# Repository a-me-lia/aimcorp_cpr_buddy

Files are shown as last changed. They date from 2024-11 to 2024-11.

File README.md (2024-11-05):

# Production Instructions

The files in the `/production` folder are ready for ordering at JLCPCB or most other PCB brokering services.

- **Board Design**: This board is designed as a 2-layer PCB. The quoting software should automatically select the minimum tolerances needed.
- **BOM Handling**: 
    - After uploading the BOM, if a component did not autopopulate, locate the corresponding designator in the BOM file.
    - Use the LCSC part number from the BOM to search in the JLC Parts library for an identical component.
    - LCSC "C-numbers" can be directly used in JLCPCB for part selection.

# Programming Instructions

This board is compatible with a standard 6-pin FTDI breakout for programming.

- **Programming Port**: The programming port is not populated with a pin header, allowing direct insertion of the FTDI board.
- **Bootloader Mode Strapping**: Refer to the [ESP-12F datasheet](https://www.espressif.com/sites/default/files/documentation/0a-esp8266ex_datasheet_en.pdf) for details on bootloader mode strapping.
    - All physical interfaces for pin strapping are accessible via a 4-pin interface on the board.

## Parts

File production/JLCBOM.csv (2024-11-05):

Comment | Designator | Footprint | JLCPCB Part #
BS-08-B2AA001 | BT1 | BS-08-B2AA001 | C964777
C100n | C1,C2,C4,C5,C6,C7 | Capacitor_SMD:C_0402_1005Metric | C60474
C1u | C3 | Capacitor_SMD:C_0402_1005Metric | C14445
BAT54C-7-F | D1 | Package_TO_SOT_SMD:SOT-23 | C556168
Conn_01x04_Pin | J2 | PinHeader_1x04_P2.54mm_Vertical | C6332197
Lf | L1 | Inductor_SMD:L_0402_1005Metric | C2885921
FNR4030S4R7MT | L2 | Inductor_SMD:L_Changjiang_FNR4030S | C167874
R330 | R1,R11,R14 | Resistor_SMD:R_0402_1005Metric | C25104
R4k7 | R2,R3,R7,R9 | Resistor_SMD:R_0402_1005Metric | C25940
R68k | R4 | Resistor_SMD:R_0402_1005Metric | C36871
R22k | R5,R13,R15 | Resistor_SMD:R_0402_1005Metric | C82868
R47k | R6 | Resistor_SMD:R_0402_1005Metric | C93943
R100R | R12 | Resistor_SMD:R_0402_1005Metric | C106232
ESP-12F | U1 | RF_Module:ESP-12E | C82891
ADS1110A0IDBVR | U2 | SOT95P280X145-6N | C16598
TPS613221ADBV | U3 | Package_TO_SOT_SMD:SOT-23-5 | C2071121

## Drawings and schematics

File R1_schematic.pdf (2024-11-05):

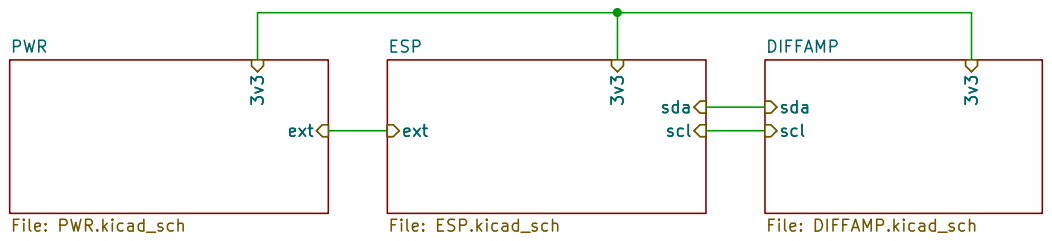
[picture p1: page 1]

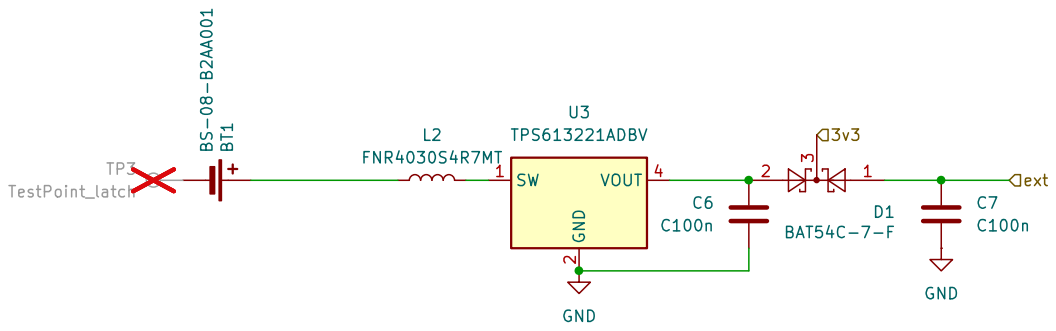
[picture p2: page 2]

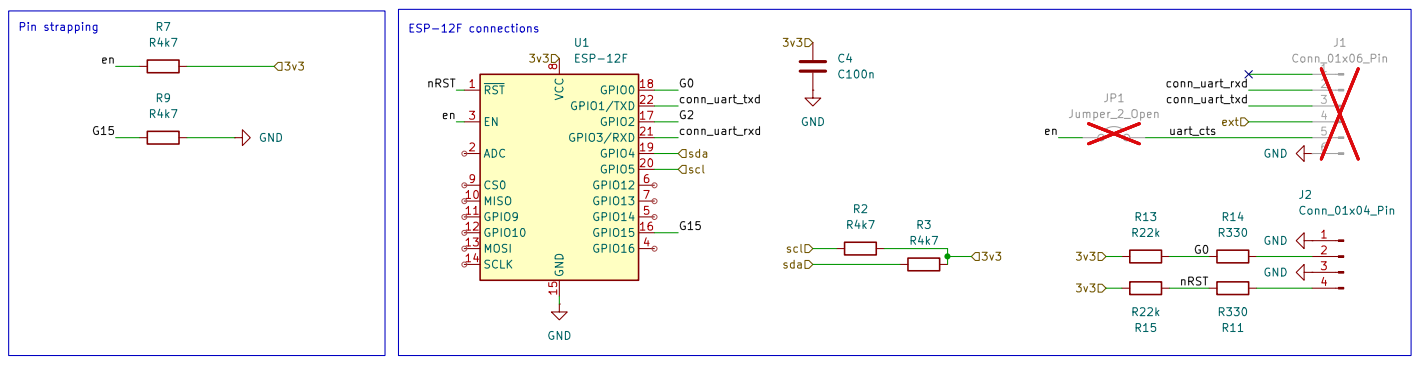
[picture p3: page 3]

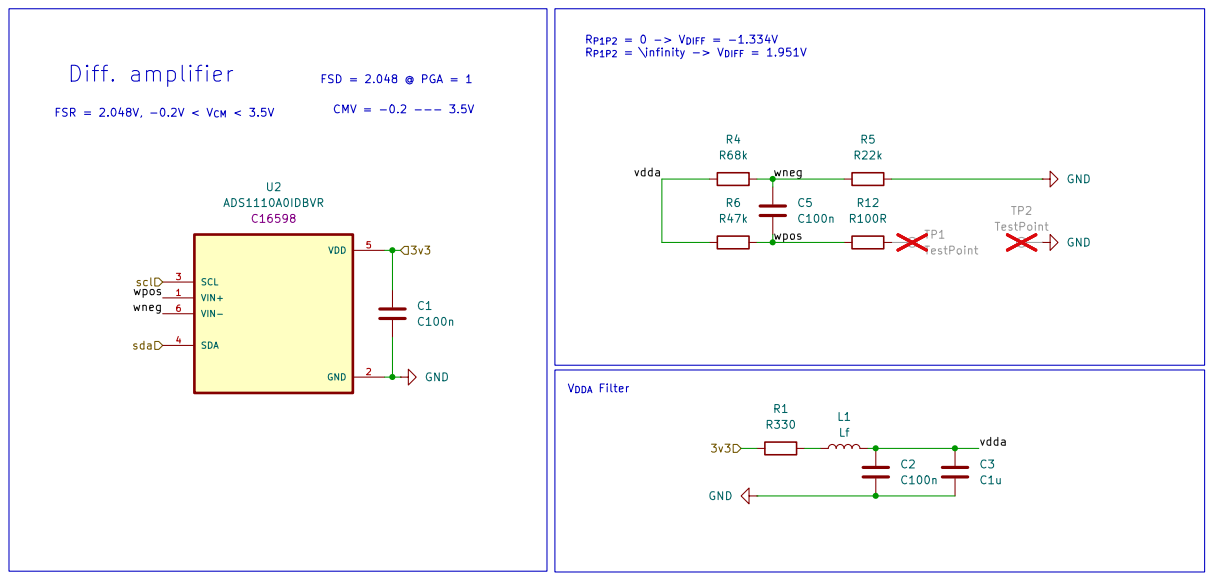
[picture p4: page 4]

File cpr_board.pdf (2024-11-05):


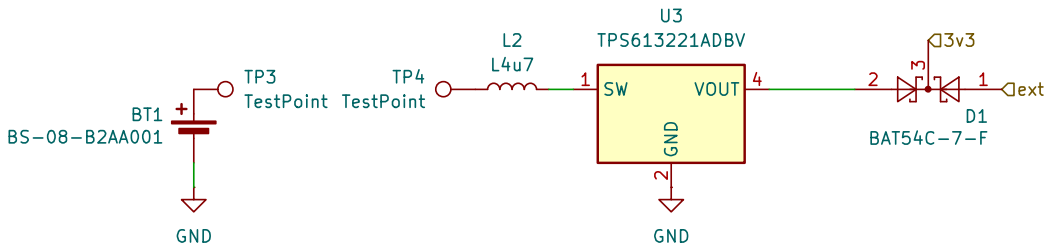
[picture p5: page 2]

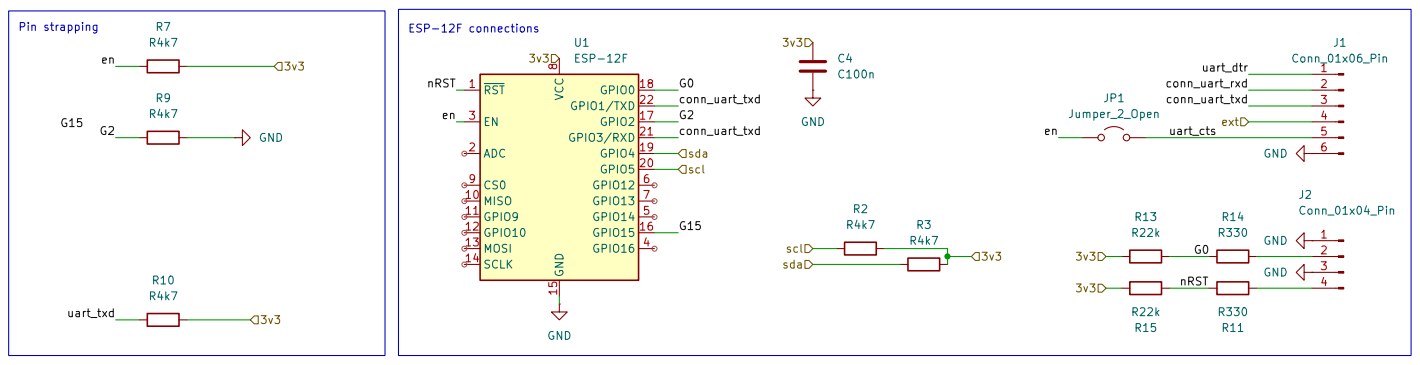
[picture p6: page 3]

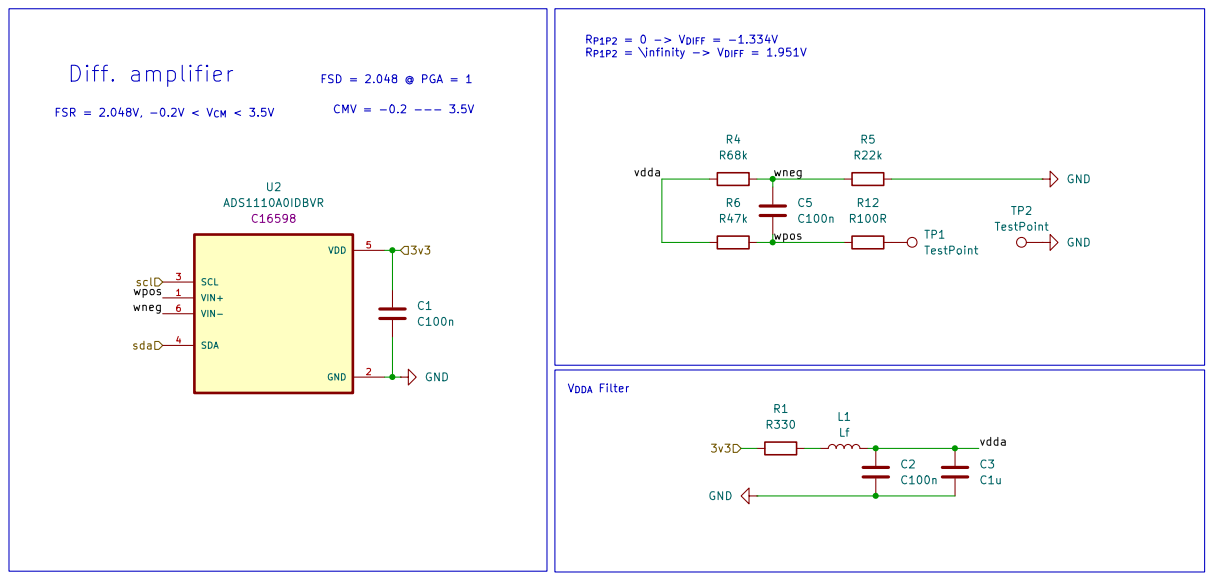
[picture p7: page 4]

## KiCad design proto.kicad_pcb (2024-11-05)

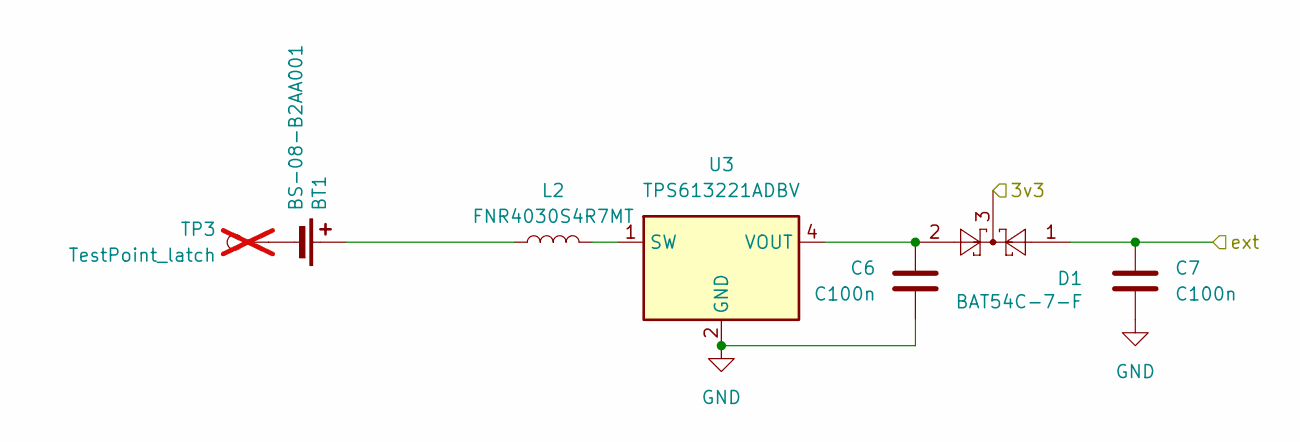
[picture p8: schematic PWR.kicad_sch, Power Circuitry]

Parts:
BT1: BS-08-B2AA001; LCSC C964777
C6, C7: C100n; C_0402_1005Metric; LCSC C60474
D1: BAT54C-7-F; SOT-23; LCSC C556168
L2: FNR4030S4R7MT; L_Changjiang_FNR4030S; LCSC C167874
TP3: TestPoint_latch; TestPoint_Bridge_Pitch2.0mm_Drill0.7mm; not fitted
U3: TPS613221ADBV; SOT-23-5; LCSC C2071121

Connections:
/DIFFAMP/3v3: D1.3; also elsewhere on the board
/ESP/ext: C7.1, D1.1; also elsewhere on the board
GND: C6.2, C7.2, U3.2 (GND); also elsewhere on the board
unnamed: BT1.+, L2.1
unnamed: BT1.-, TP3.1
unnamed: L2.2, U3.1 (SW)
unnamed: C6.1, D1.2, U3.4 (VOUT)

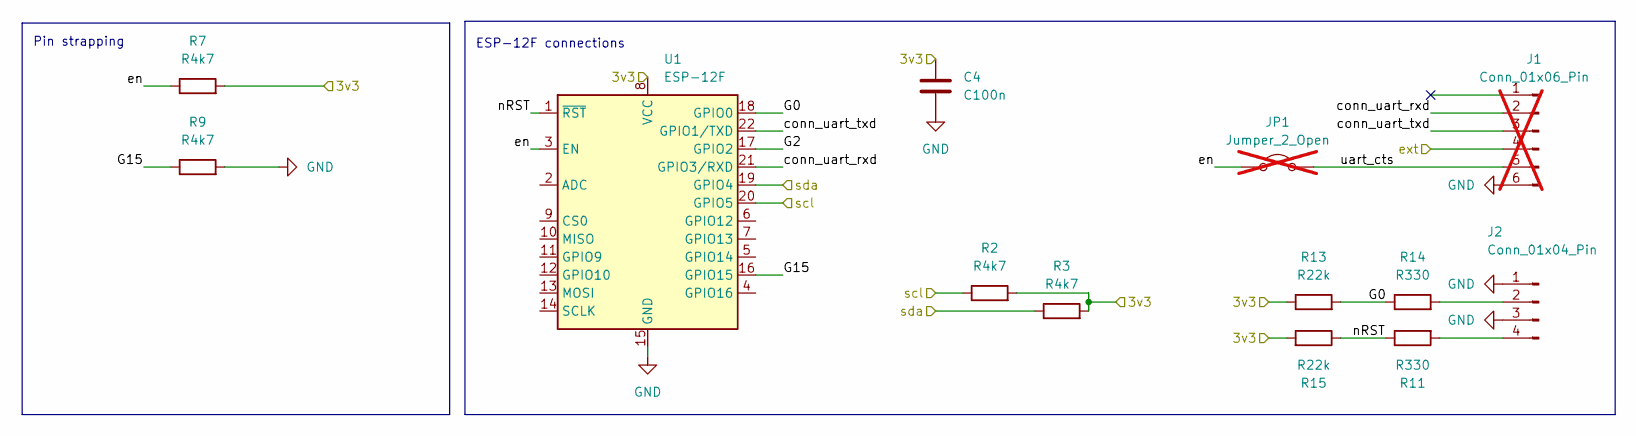
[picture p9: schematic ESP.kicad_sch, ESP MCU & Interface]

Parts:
C4: C100n; C_0402_1005Metric; LCSC C60474
J1: Conn_01x06_Pin; PinHeader_1x06_P2.54mm_Vertical; not fitted
J2: Conn_01x04_Pin; PinHeader_1x04_P2.54mm_Vertical; LCSC C6332197
JP1: Jumper_2_Open; SolderJumper-2_P1.3mm_Open_TrianglePad1.0x1.5mm; not fitted
R2, R3, R7, R9: R4k7; R_0402_1005Metric; LCSC C25940
R11, R14: R330; R_0402_1005Metric; LCSC C25104
R13, R15: R22k; R_0402_1005Metric; LCSC C82868
U1: ESP-12F; ESP-12E; LCSC C82891

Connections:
/DIFFAMP/3v3: C4.1, R2.2, R3.2, R7.2, R13.1, R15.2, U1.8 (VCC); also elsewhere on the board
/DIFFAMP/scl: R2.1, U1.20 (GPIO5); also elsewhere on the board
/DIFFAMP/sda: R3.1, U1.19 (GPIO4); also elsewhere on the board
/ESP/G0: R13.2, R14.1, U1.18 (GPIO0)
/ESP/G2: U1.17 (GPIO2)
/ESP/G15: R9.1, U1.16 (GPIO15)
/ESP/conn_uart_rxd: J1.2, U1.21 (GPIO3/RXD)
/ESP/conn_uart_txd: J1.3, U1.22 (GPIO1/TXD)
/ESP/en: JP1.1 (A), R7.1, U1.3 (EN)
/ESP/ext: J1.4; also elsewhere on the board
/ESP/nRST: R11.1, R15.1, U1.1 (~RST)
/ESP/uart_cts: J1.5, JP1.2 (B)
GND: C4.2, J1.6, J2.1, J2.3, R9.2, U1.15 (GND); also elsewhere on the board
unnamed: J2.2, R14.2
unnamed: J2.4, R11.2

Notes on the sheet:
Pin strapping
ESP-12F connections

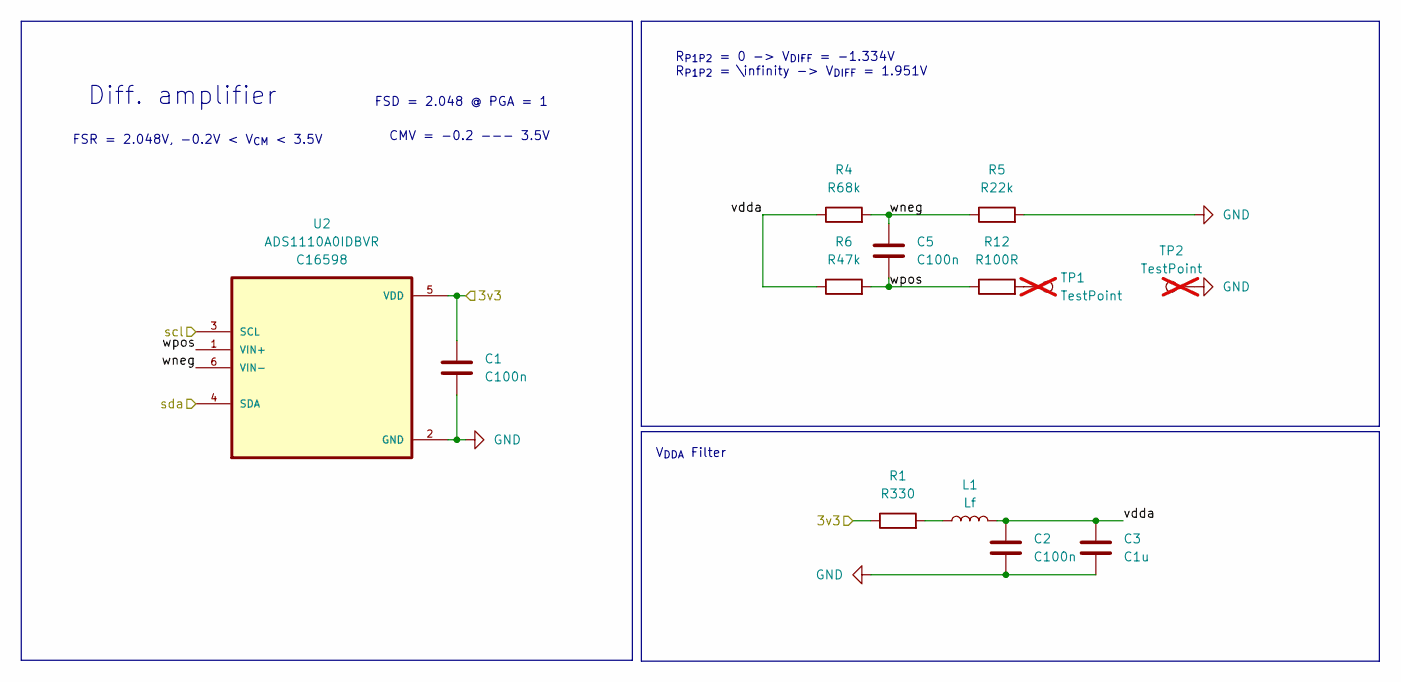
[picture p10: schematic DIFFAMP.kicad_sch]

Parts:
C1, C2, C5: C100n; C_0402_1005Metric; LCSC C60474
C3: C1u; C_0402_1005Metric; LCSC C14445
L1: Lf; L_0402_1005Metric; LCSC C2885921
R1: R330; R_0402_1005Metric; LCSC C25104
R4: R68k; R_0402_1005Metric; LCSC C36871
R5: R22k; R_0402_1005Metric; LCSC C82868
R6: R47k; R_0402_1005Metric; LCSC C93943
R12: R100R; R_0402_1005Metric; LCSC C106232
TP1, TP2: TestPoint; not fitted
U2: ADS1110A0IDBVR; SOT95P280X145-6N; LCSC C16598

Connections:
/DIFFAMP/3v3: C1.1, R1.1, U2.5 (VDD); also elsewhere on the board
/DIFFAMP/scl: U2.3 (SCL); also elsewhere on the board
/DIFFAMP/sda: U2.4 (SDA); also elsewhere on the board
/DIFFAMP/vdda: C2.1, C3.1, L1.2, R4.1, R6.1
/DIFFAMP/wneg: C5.1, R4.2, R5.1, U2.6 (VIN-)
/DIFFAMP/wpos: C5.2, R6.2, R12.1, U2.1 (VIN+)
GND: C1.2, C2.2, C3.2, R5.2, TP2.1, U2.2 (GND); also elsewhere on the board
unnamed: L1.1, R1.2
unnamed: R12.2, TP1.1

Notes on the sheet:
FSR = 2.048V, -0.2V < V_{CM} < 3.5V
V_{DDA} Filter
R_{P1P2} = 0 -> V_{DIFF} = -1.334V R_{P1P2} = \infinity -> V_{DIFF} = 1.951V
FSD = 2.048 @ PGA = 1
CMV = -0.2 --- 3.5V
Diff. amplifier

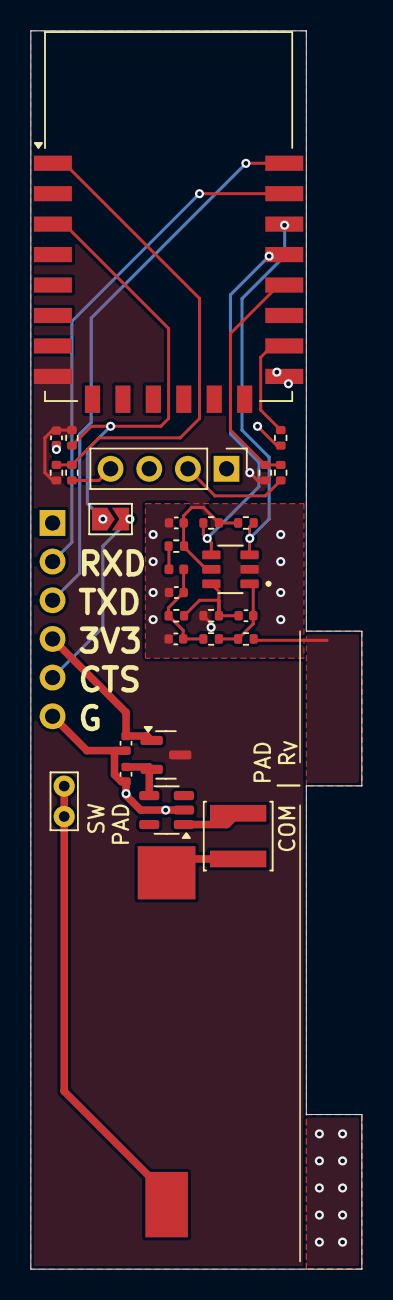
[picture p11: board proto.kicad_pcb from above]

Board: 2 copper layers, 21.8 x 81.3 mm, 31 parts (0 on the bottom side), 22 nets.
